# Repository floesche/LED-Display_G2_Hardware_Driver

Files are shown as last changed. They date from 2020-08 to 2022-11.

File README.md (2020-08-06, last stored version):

---
title: LED Array PCBs
parent: Generation 2
---

## Project content

```
├── led_array_3mm
│   └── gerber_v0p1
├── led_array_3mm_spacer
├── led_array_5mm
│   └── gerber_v0p1
├── led_array_5mm_adaptor
│   └── gerber_v0p1
├── led_array_5mm_mask
│   ├── arrayed
│   └── single
├── led_array_8x8_template
├── led_array_mixed
│   ├── gerber_v0p1
│   └── gerber_v0p2
├── led_array_sm0805
│   └── gerber_v0p1
└── pass_thru_panel
    └── gerber_v1p0
```

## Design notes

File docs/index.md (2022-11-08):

---
title: LED matrix
parent: Generation 2
nav_order: 5
---

# Custom LED matrix boards

Different pre-fabricated LED matrices are available, but their emitted light spectrum is not always well specified, might differ between production batches, and don't always align well with the sensitivity of a drosophila visual system. Around 2013 there was an effort to produce custom LED matrices for [Generation 2]({{site.baseurl}}/G2/) and [Generation 3]({{site.baseurl}}/G3/) display systems. The different versions listed below are plug-in replacements for pre-fabricated LED matrices and designed to be used with the [panel boards]({{site.baseurl}}/Generation%202/Panels/docs/).

1. TOC
{:toc}

## LED array TH 3mm

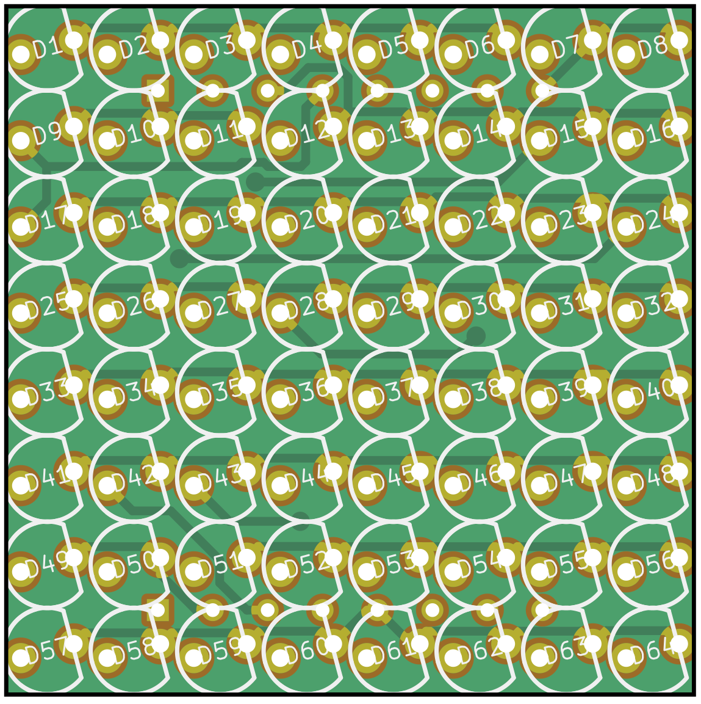
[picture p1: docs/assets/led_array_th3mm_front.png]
LED array through hole 3mm

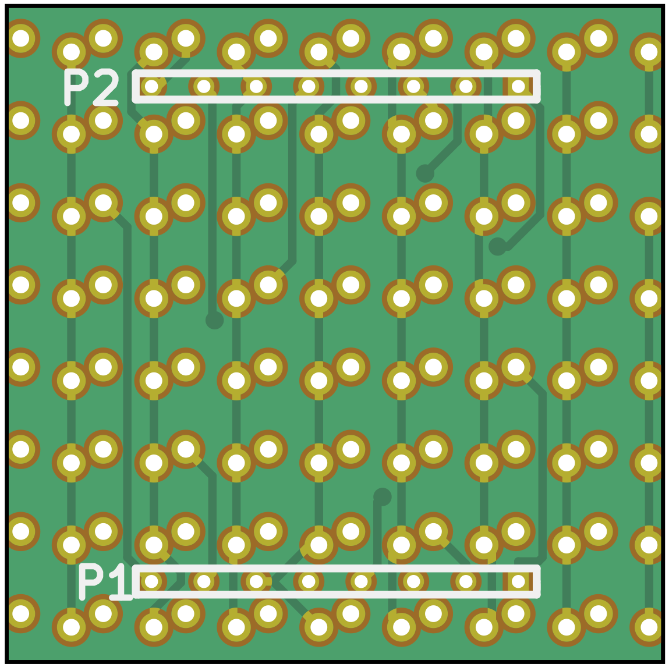
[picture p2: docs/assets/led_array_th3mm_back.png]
LED array through hole 3mm


The LED array TH 3mm is a LED matrix for through hole (TH) 3mm LEDs (have a [look at the schematics](assets/led_array_th3mm_schematic.pdf)). LEDs from many different manufacturers are available in this packages size.

Historic production ready files are archived at `led_array_th3mm/production_v1/`, yet it is unclear if there was ever a PCB produced.

The folder `led_array_th3mm/objects/` contains a vector graphic file, presumably used to laser cut a spacer to be used on top of the PCB (see [preview pdf](assets/led_array_th3mm_spacer.pdf)).

## LED array TH 5mm

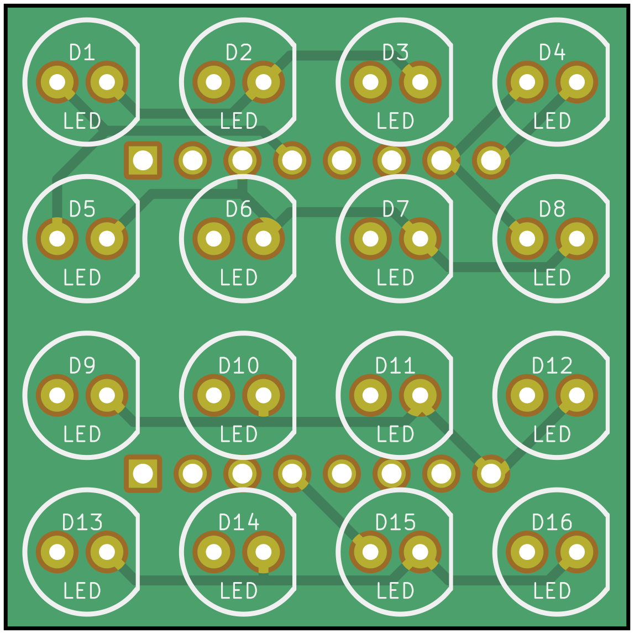
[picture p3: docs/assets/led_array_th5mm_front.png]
LED array through hole 5mm

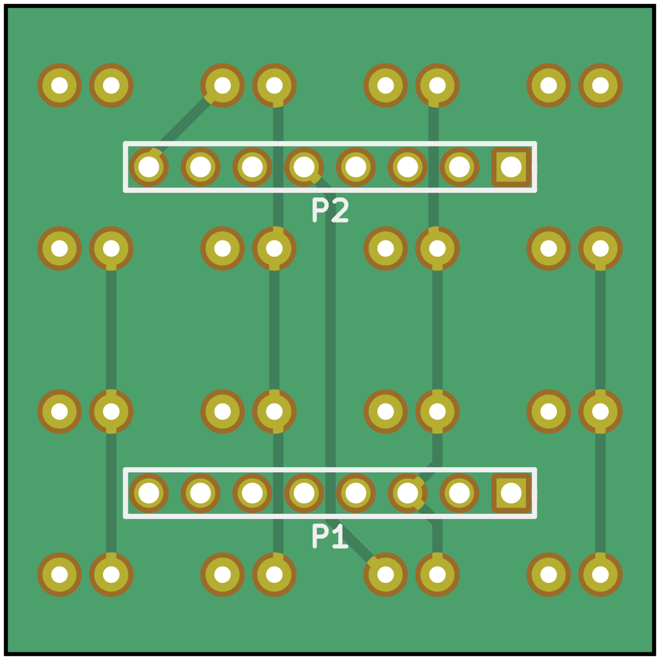
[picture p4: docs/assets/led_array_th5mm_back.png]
LED array through hole 5mm


The LED array TH 3mm is a LED matrix for through hole (TH) 5mm LEDs (have a [look at the schematics](assets/led_array_th5mm_schematic.pdf)). LEDs from many different manufacturers are available in this packages size. Because of the size constraints, only 4×4 LEDs fit on one of these matrices.

Historic production ready files are archived at `led_array_th5mm/production_v1/`, yet it is unclear if there was ever a PCB produced.

The folder `led_array_th5mm/objects/` contains different vector graphic file, presumably used to laser cut masks for the LEDs (see [preview pdf](assets/mask_inner_5mm.pdf)).

## LED array SMD 0805

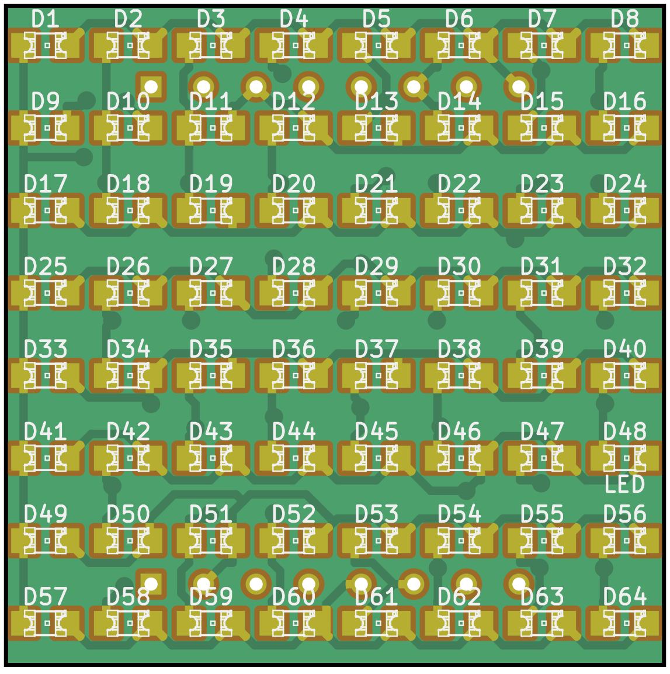
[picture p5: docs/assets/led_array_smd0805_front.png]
LED array SMD 0805

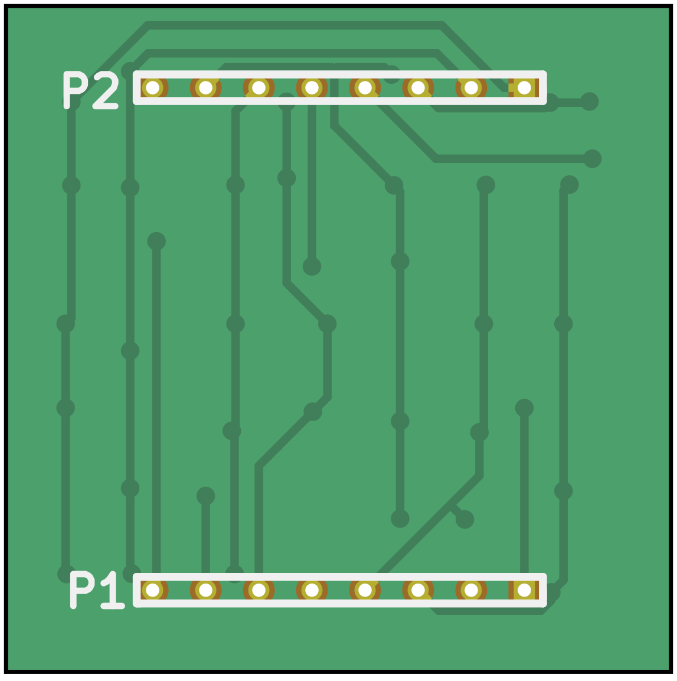
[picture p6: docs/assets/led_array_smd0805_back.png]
LED array SMD 0805


The LED array SMD 0805 is a LED matrix for surface mount devices with a package size of 0805 (have a [look at the schematics](assets/led_array_smd0805_schematic.pdf)). LEDs from many different manufacturers are available in this packages size.

Historic production ready files are archived at `led_array_smd0805/production_v1/`, yet it is unclear if there was ever a PCB produced.

## LED array SMD 1411-0805

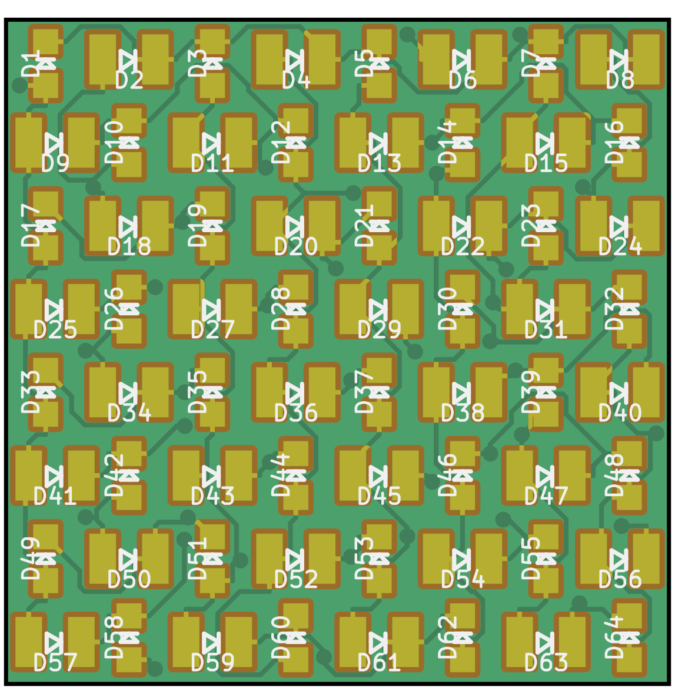
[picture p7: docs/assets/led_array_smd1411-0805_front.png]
LED array SMD 1411-0805

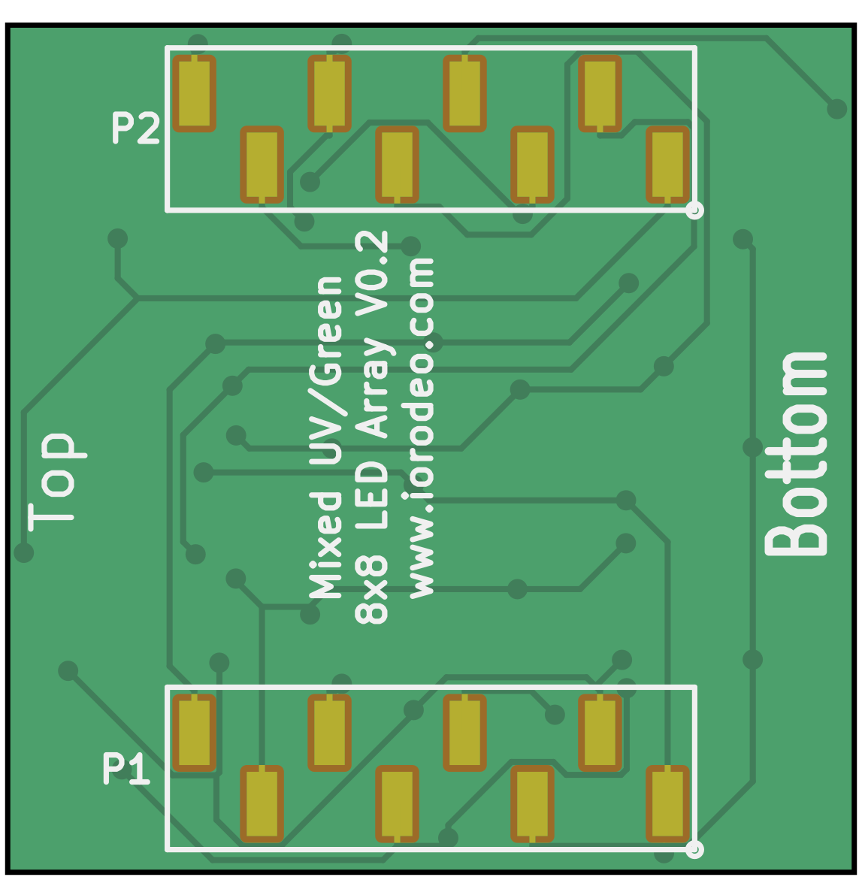
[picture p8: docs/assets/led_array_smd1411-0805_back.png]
LED array SMD 1411-0805


The LED array SMD 1411-0805 is a LED matrix for surface mount devices with alternating between packages size of 1411 and 0805 (have a [look at the schematics](assets/led_array_smd1411-0805_schematic.pdf)). This LED matrix was designer to use UV and green LEDs in the same matrix. The chosen UV LED by Yuli Tech with a spectrum peak at 365nm and product number __YLUV-365SMD__ has a SMD 1411 package size. There is a wide range of green LEDs in an 0805 package available, such as the Rohm __SML-210MTT86__ with a spectrum peak at 570nm.

Historic production ready files are archived at `led_array_smd0805/production_v0`. The most recently produced version was `led_array_smd1411-0805_v0p2.zip`.

## LED array template

The project folder `led_array_template` contains a 8×8 schematic that can be used as a template to produce different types of PCBs.

## Panel Adaptor

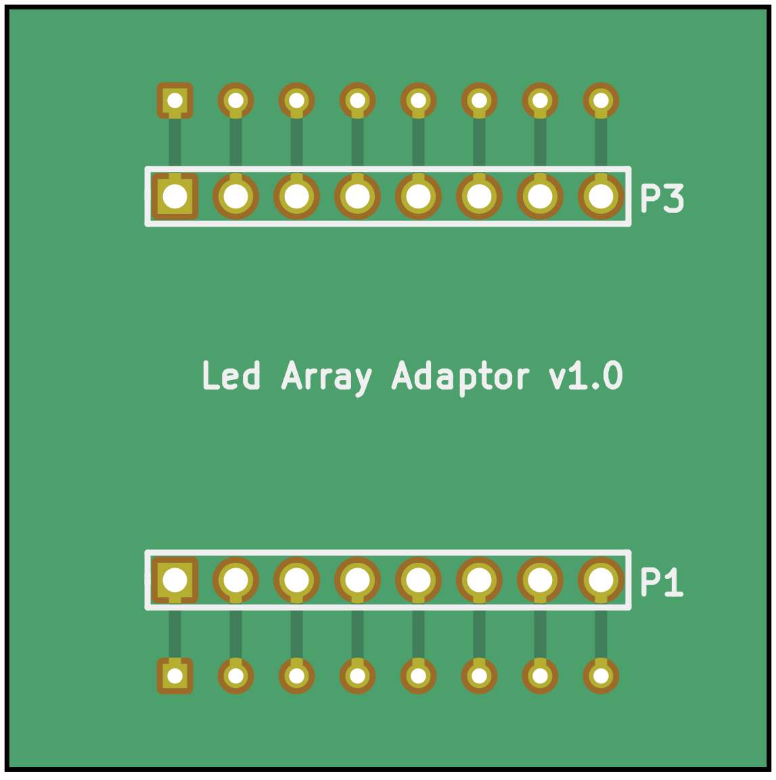
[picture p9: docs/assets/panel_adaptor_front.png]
Panel Adaptor Front

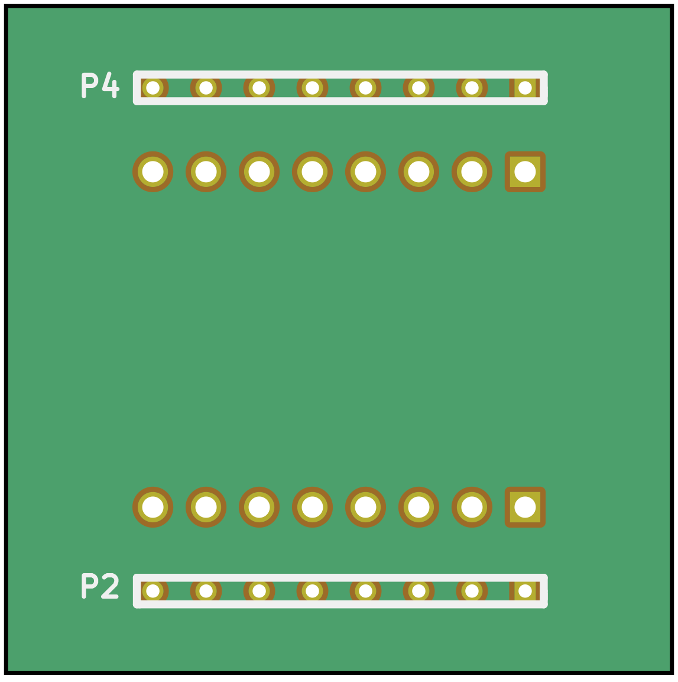
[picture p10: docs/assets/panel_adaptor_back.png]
Panel Adaptor Back


The `panel_adaptor` is a small PCB that allows an adaptation between different matrix sized and the [panel board]({{site.baseurl}}/Generation%202/Panels/docs/).

## Panel pass-thru

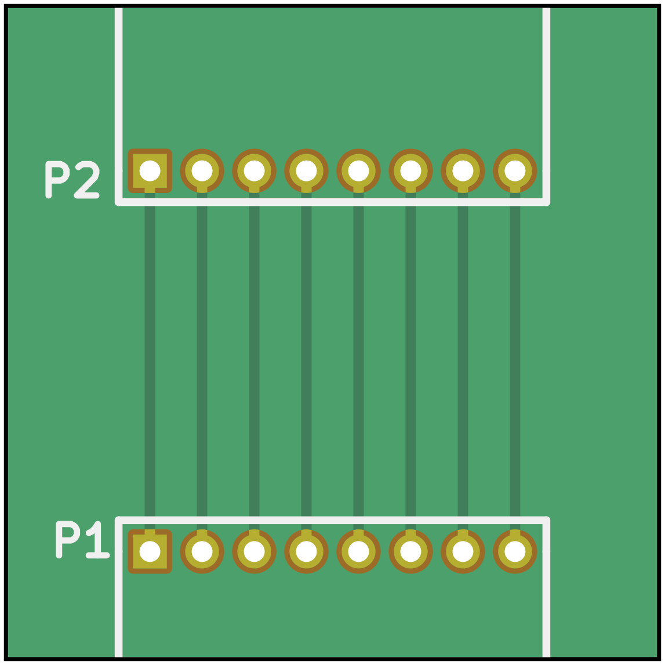
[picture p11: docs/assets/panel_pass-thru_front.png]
Panel pass-thru Front

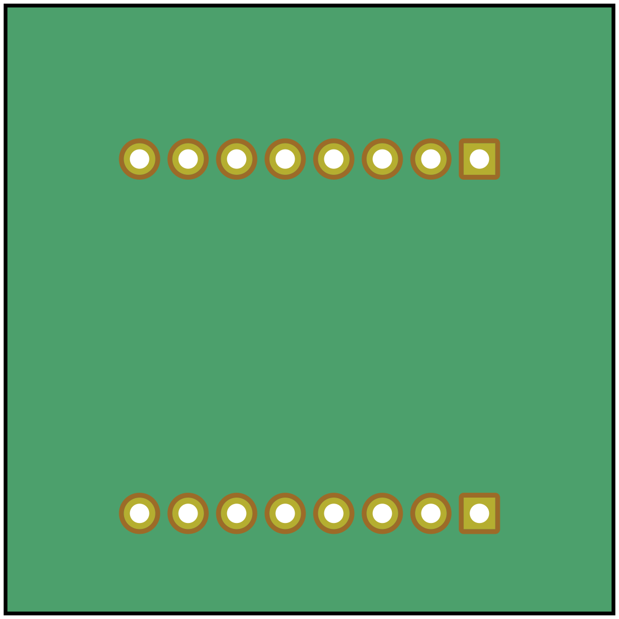
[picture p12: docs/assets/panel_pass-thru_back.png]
Panel pass-thru Back


The `panel_pass-thru` is a drop in replacement for a single display module. It carries the electrical signal to the next module, but does not display anything. This is similar to the [Generation 4 Window]({{site.baseurl}}/Generation%204/Hardware/docs/comm.html#window), but without the cutout in the center.

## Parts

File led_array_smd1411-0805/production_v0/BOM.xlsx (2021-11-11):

Item # | Qty | Reference | Descritpion | P/N | Vendor
1 | 32 | D1, D3, D5, D7, D10, D12, D14, D16, D17, D19, D21, D23, D26, D28, D30, D32, D33, D35, D37, D39, D42, D44, D46, D48, D49, D51, D53, D55, D58, D60, D62, D64 | LED 570nm (green) SMD 0805 | 511-1287-1-ND | Digikey
2 | 32 | D2, D4, D6, D8, D9, D11, D13, D15, D18, D20, D22, D24, D25, D27, D29, D31, D34, D36, D38, D40, D41, D43, D45, D47, D50, D52, D54, D56, D57, D59, D61, D63 | LED 365nm (UV) SMD | YLUV-365SMD | Shanghai Yuli Technology Co., Ltd (For contact information see below)
3 | 2 | P1, P2 | SMD header – 8 pos made from 64 pos breakaway | ED24064-ND | Digikey
Notes:
1.) Components P1 and P2 on the back side of the PCB are not to be included in the turn-key assembly.
2.) Shanghai Yuli Technology Co., Ltd. Contact: Luna Tang, Email: sales@yulitech.com, Tel: 0086 -21 33632320, Fax: 0086 21 33632320

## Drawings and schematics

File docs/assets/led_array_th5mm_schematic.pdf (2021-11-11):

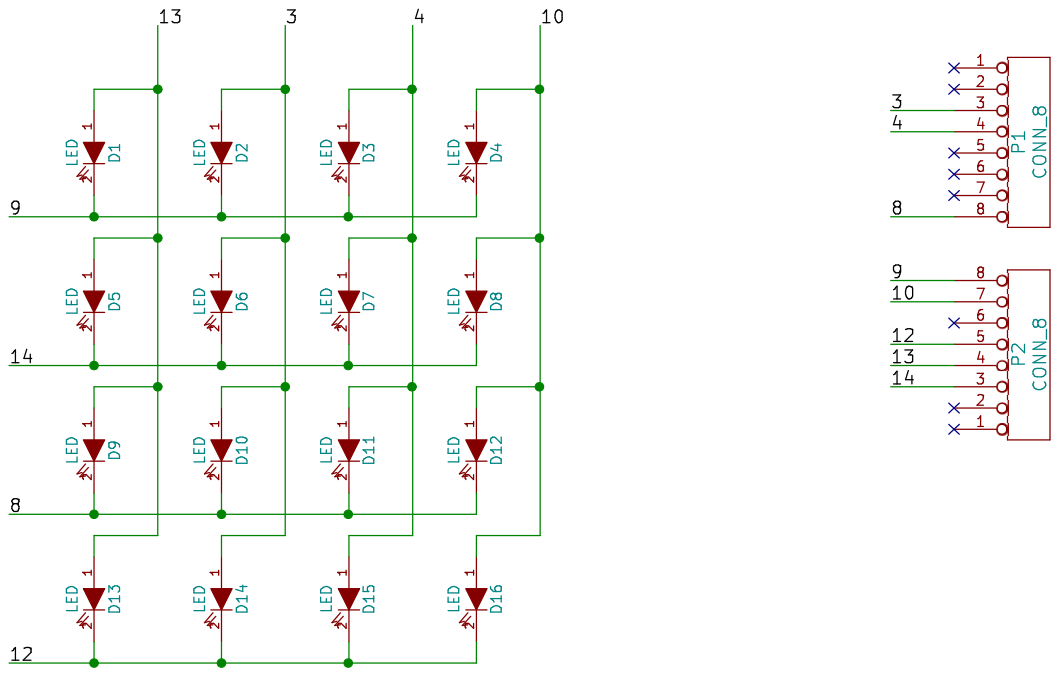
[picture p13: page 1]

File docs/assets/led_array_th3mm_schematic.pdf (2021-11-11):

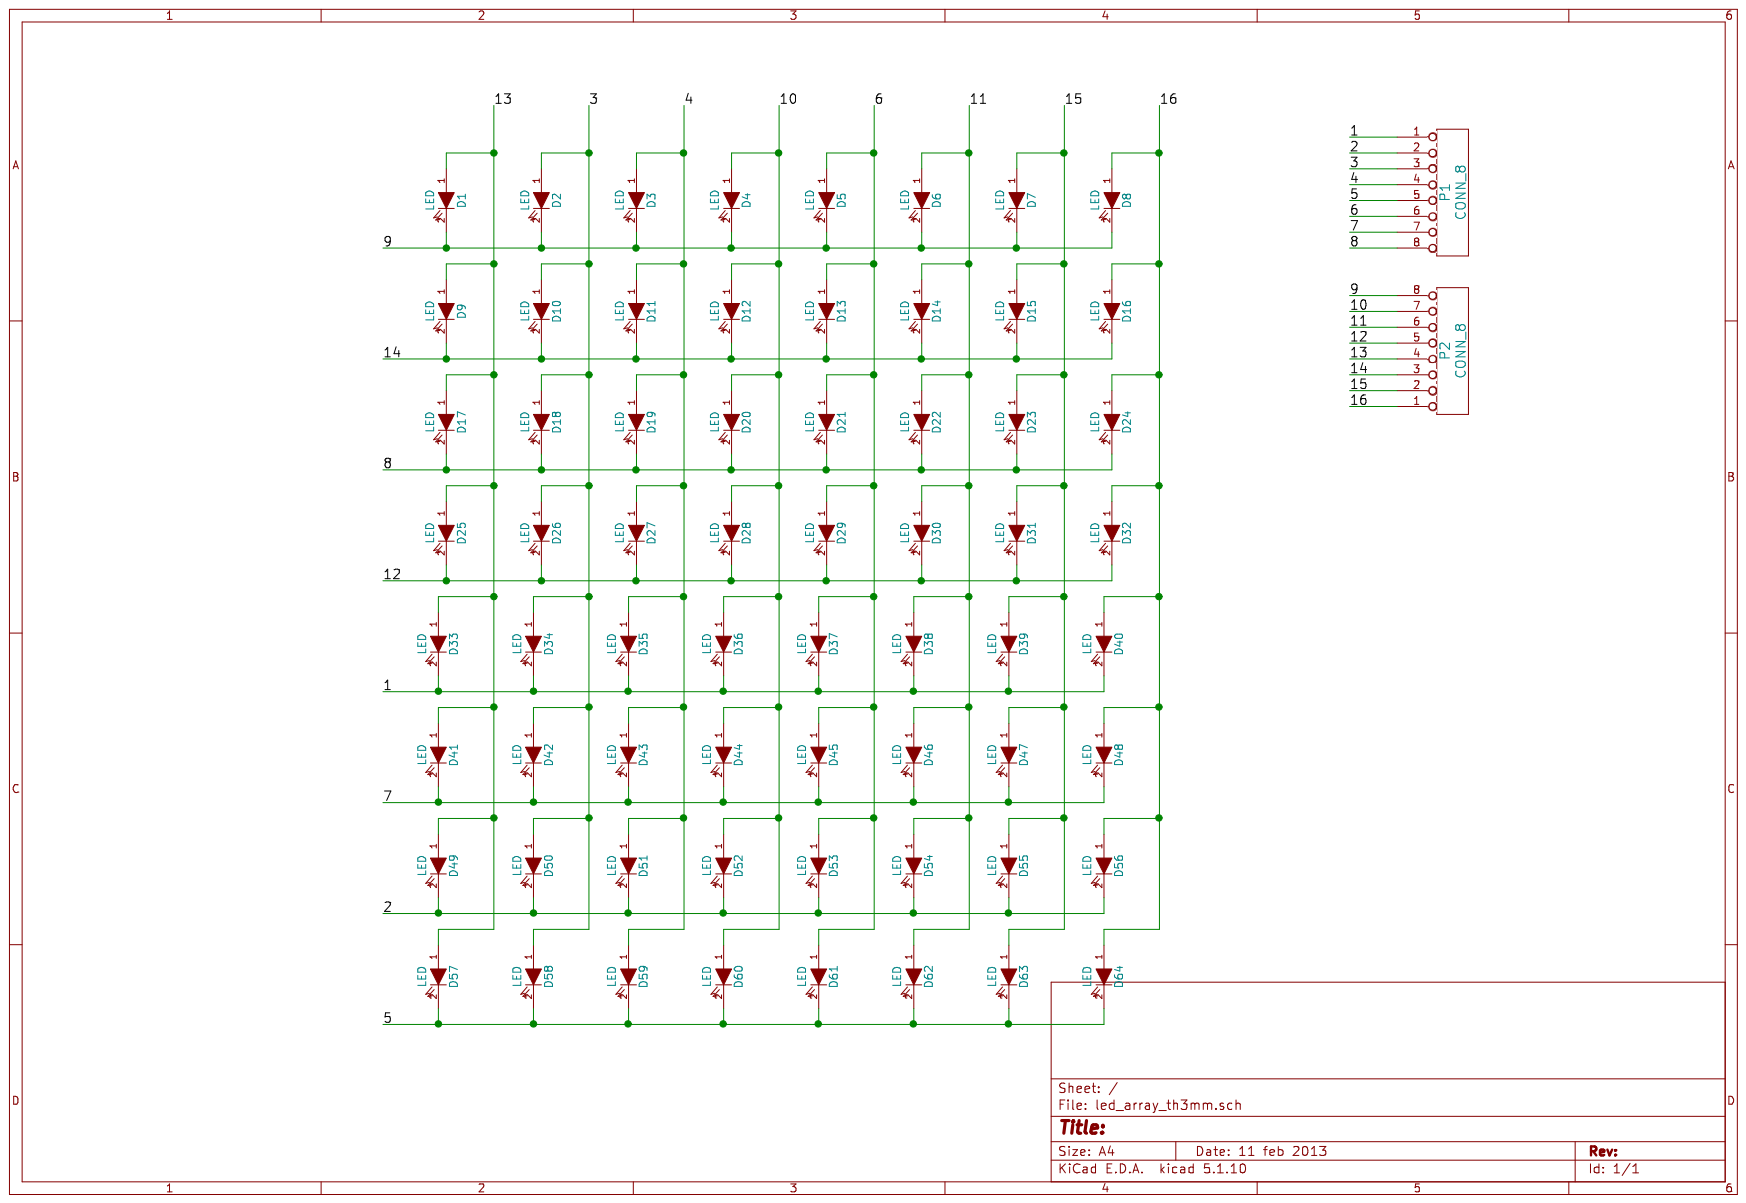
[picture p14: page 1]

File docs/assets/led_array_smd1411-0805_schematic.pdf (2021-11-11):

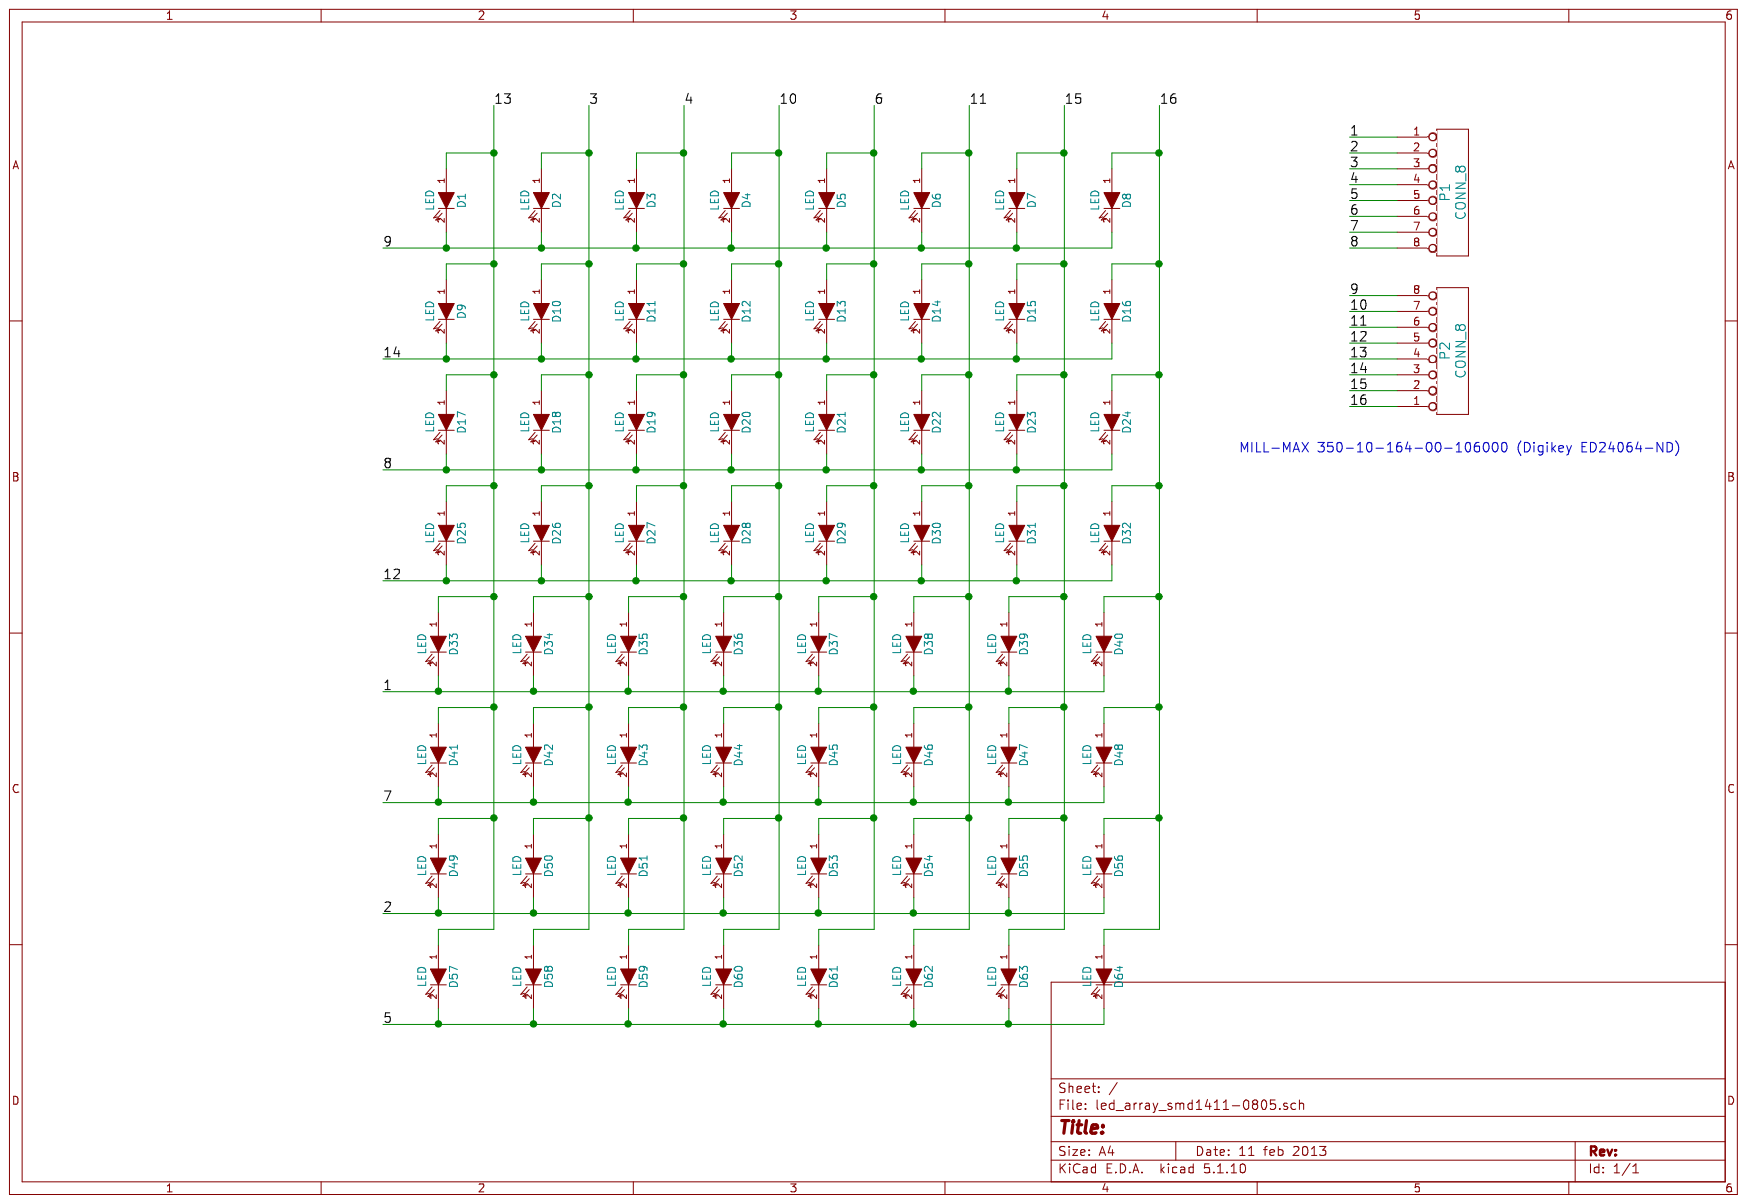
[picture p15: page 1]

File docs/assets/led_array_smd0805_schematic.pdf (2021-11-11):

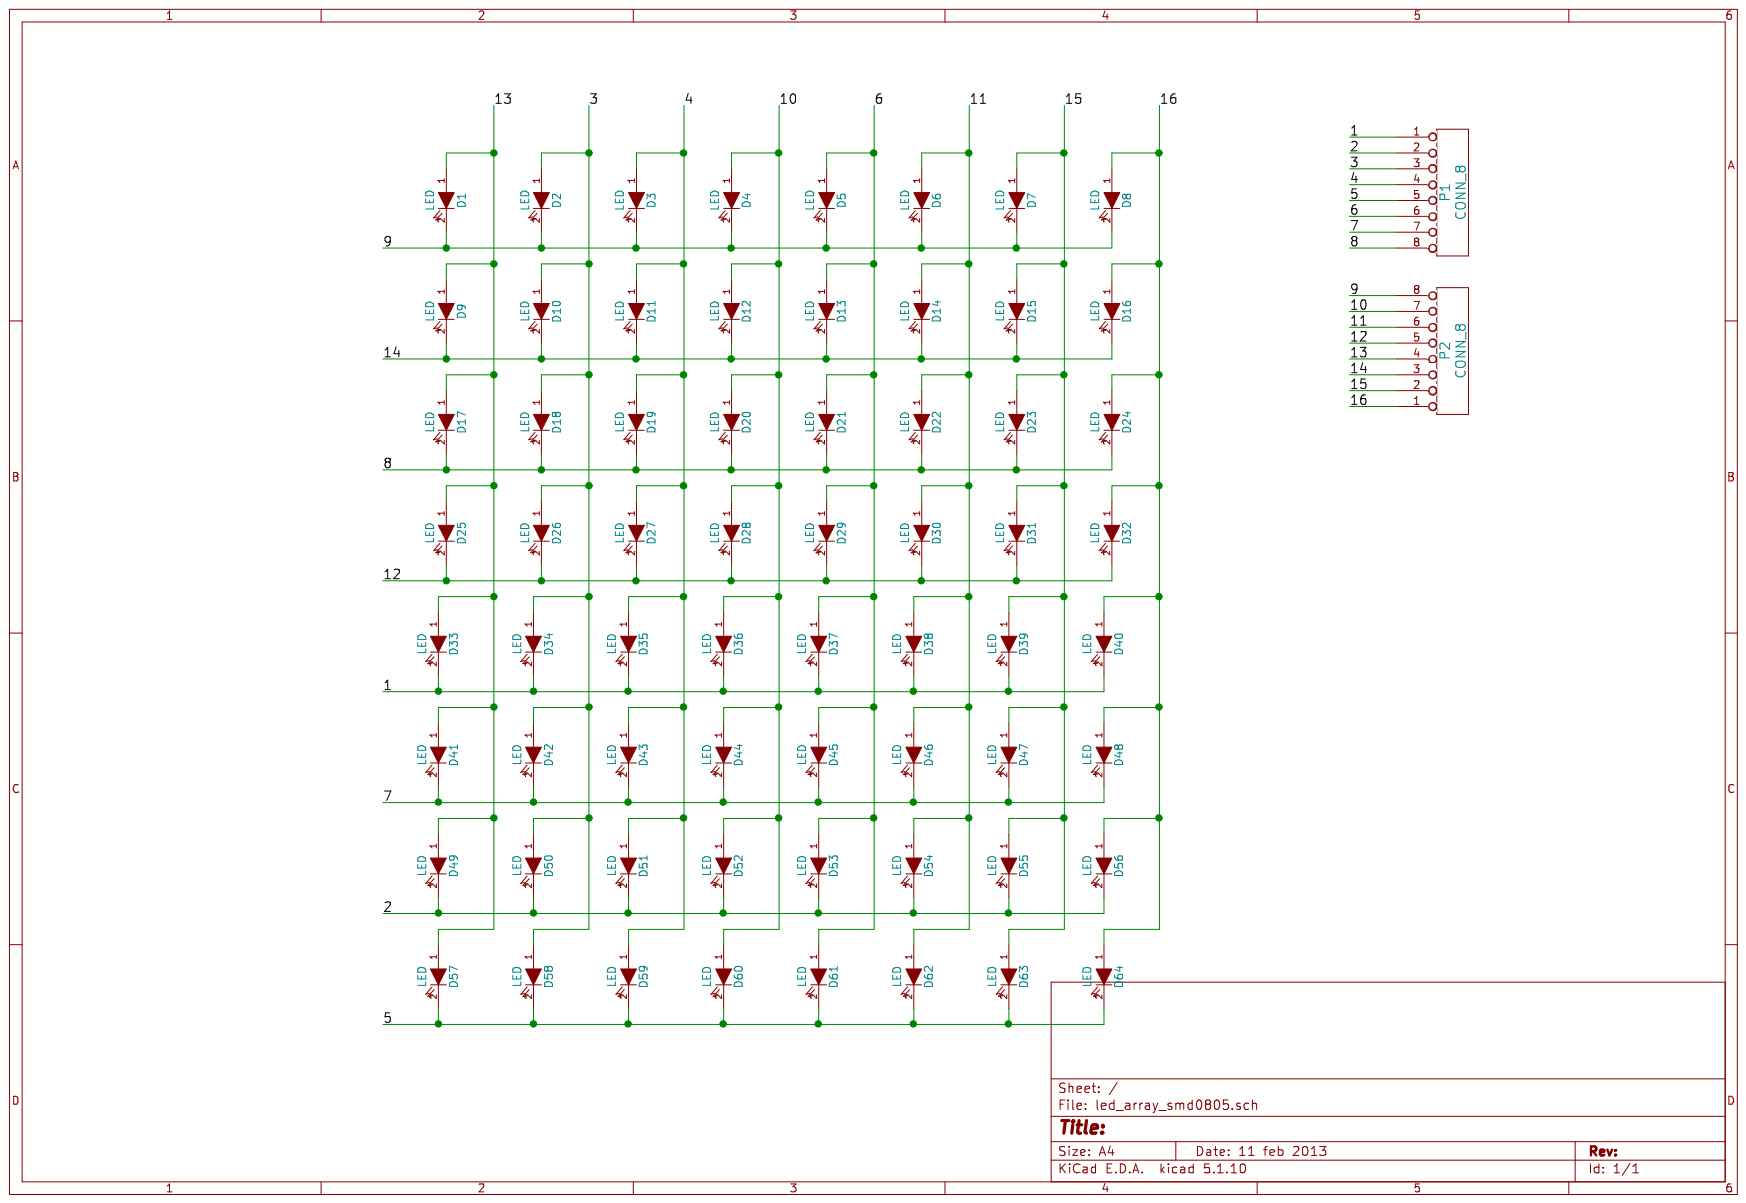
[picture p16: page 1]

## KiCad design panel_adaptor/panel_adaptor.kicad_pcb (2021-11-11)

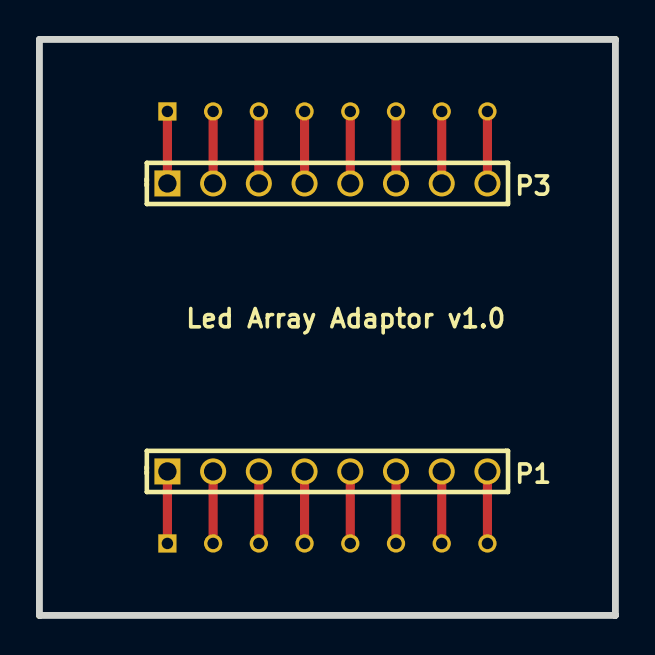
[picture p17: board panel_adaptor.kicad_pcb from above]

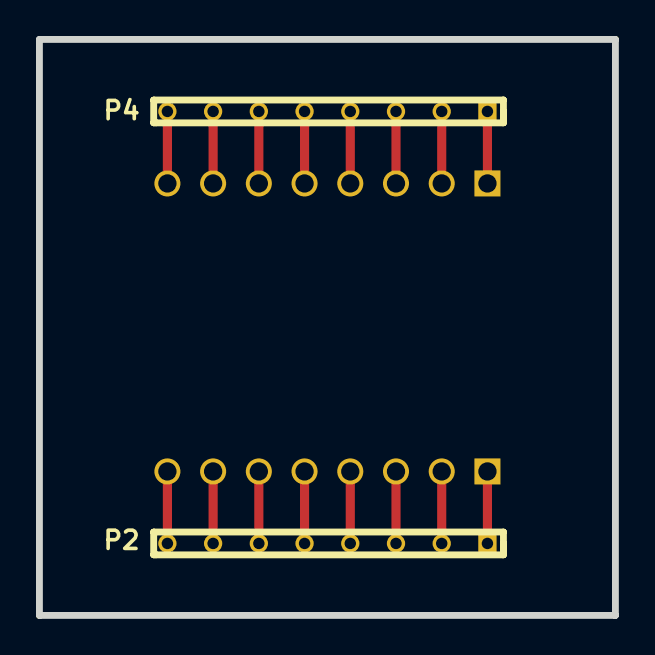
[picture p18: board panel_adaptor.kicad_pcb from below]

Board: 2 copper layers, 32.0 x 32.0 mm, 4 parts (2 on the bottom side), 16 nets.

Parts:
P1, P3: PIN_ARRAY-8X1
P2, P4: PANEL_HEADER_8PIN

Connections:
unnamed: P3.1, P4.1
unnamed: P3.2, P4.2
unnamed: P3.3, P4.3
unnamed: P3.4, P4.4
unnamed: P3.5, P4.5
unnamed: P3.6, P4.6
unnamed: P3.7, P4.7
unnamed: P3.8, P4.8
unnamed: P1.1, P2.1
unnamed: P1.2, P2.2
unnamed: P1.3, P2.3
unnamed: P1.4, P2.4
unnamed: P1.5, P2.5
unnamed: P1.6, P2.6
unnamed: P1.7, P2.7
unnamed: P1.8, P2.8

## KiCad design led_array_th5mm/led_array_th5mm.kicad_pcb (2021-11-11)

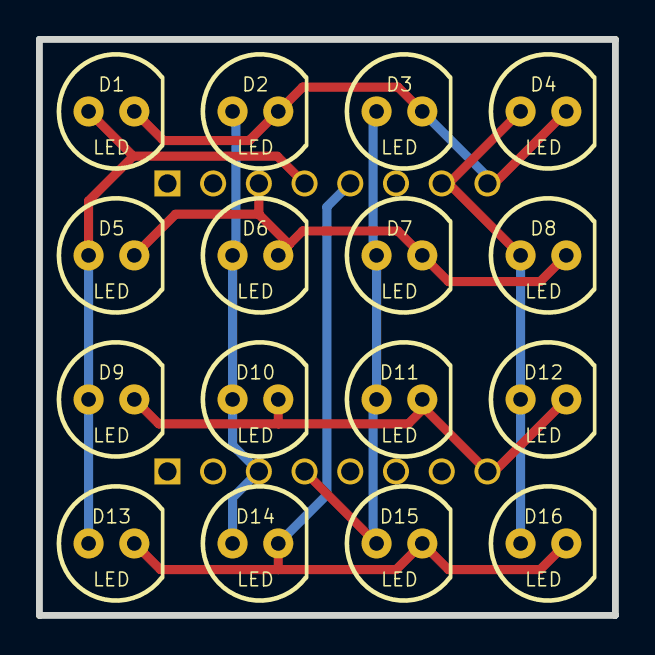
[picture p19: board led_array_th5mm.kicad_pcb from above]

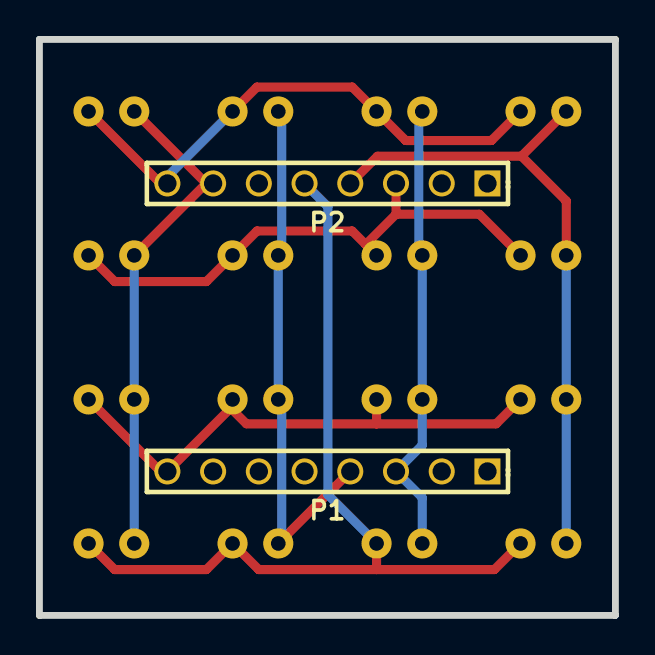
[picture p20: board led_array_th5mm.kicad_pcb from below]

Board: 2 copper layers, 32.0 x 32.0 mm, 18 parts (2 on the bottom side), 8 nets.

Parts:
D1, D2, D3, D4, D5, D6, D7, D8, D9, D10, D11, D12, D13, D14, D15, D16: LED; LED-5MM-MOD
P1, P2: PIN_ARRAY-8X1

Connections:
/3: D2.1, D6.1, D10.1, D14.1, P1.3
/4: D3.1, D7.1, D11.1, D15.1, P1.4
/8: D9.2, D10.2, D11.2, D12.2, P1.8
/9: D1.2, D2.2, D3.2, D4.2, P2.8
/10: D4.1, D8.1, D12.1, D16.1, P2.7
/12: D13.2, D14.2, D15.2, D16.2, P2.5
/13: D1.1, D5.1, D9.1, D13.1, P2.4
/14: D5.2, D6.2, D7.2, D8.2, P2.3

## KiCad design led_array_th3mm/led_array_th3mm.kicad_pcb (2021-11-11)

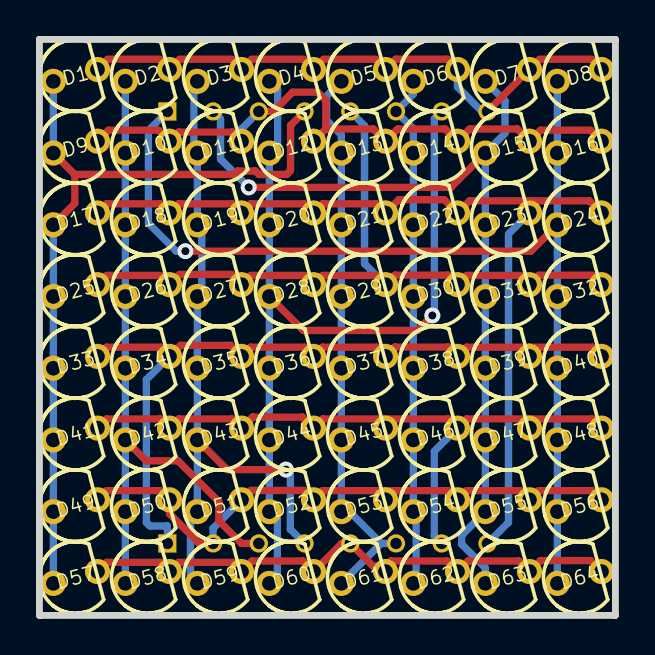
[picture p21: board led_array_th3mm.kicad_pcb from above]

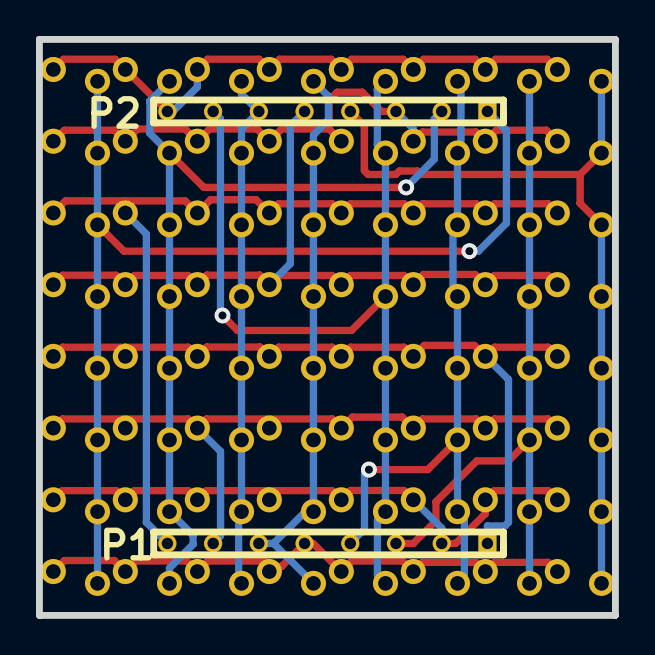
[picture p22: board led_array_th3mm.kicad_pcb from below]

Board: 2 copper layers, 32.0 x 32.0 mm, 66 parts (2 on the bottom side), 16 nets.

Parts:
D1, D2, D3, D4, D5, D6, D7, D8, D9, D10, D11, D12, D13, D14, D15, D16, D17, D18, D19, D20, D21, D22, D23, D24, D25, D26, D27, D28, D29, D30, D31, D32, D33, D34, D35, D36, D37, D38, D39, D40, D41, D42, D43, D44, D45, D46, D47, D48, D49, D50, D51, D52, D53, D54, D55, D56, D57, D58, D59, D60, D61, D62, D63, D64: LED; LED-3MM-MOD
P1, P2: PANEL_HEADER_8PIN

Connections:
/1: D33.2, D34.2, D35.2, D36.2, D37.2, D38.2, D39.2, D40.2, P1.1
/2: D49.2, D50.2, D51.2, D52.2, D53.2, D54.2, D55.2, D56.2, P1.2
/3: D2.1, D10.1, D18.1, D26.1, D34.1, D42.1, D50.1, D58.1, P1.3
/4: D3.1, D11.1, D19.1, D27.1, D35.1, D43.1, D51.1, D59.1, P1.4
/5: D57.2, D58.2, D59.2, D60.2, D61.2, D62.2, D63.2, D64.2, P1.5
/6: D5.1, D13.1, D21.1, D29.1, D37.1, D45.1, D53.1, D61.1, P1.6
/7: D41.2, D42.2, D43.2, D44.2, D45.2, D46.2, D47.2, D48.2, P1.7
/8: D17.2, D18.2, D19.2, D20.2, D21.2, D22.2, D23.2, D24.2, P1.8
/9: D1.2, D2.2, D3.2, D4.2, D5.2, D6.2, D7.2, D8.2, P2.8
/10: D4.1, D12.1, D20.1, D28.1, D36.1, D44.1, D52.1, D60.1, P2.7
/11: D6.1, D14.1, D22.1, D30.1, D38.1, D46.1, D54.1, D62.1, P2.6
/12: D25.2, D26.2, D27.2, D28.2, D29.2, D30.2, D31.2, D32.2, P2.5
/13: D1.1, D9.1, D17.1, D25.1, D33.1, D41.1, D49.1, D57.1, P2.4
/14: D9.2, D10.2, D11.2, D12.2, D13.2, D14.2, D15.2, D16.2, P2.3
/15: D7.1, D15.1, D23.1, D31.1, D39.1, D47.1, D55.1, D63.1, P2.2
/16: D8.1, D16.1, D24.1, D32.1, D40.1, D48.1, D56.1, D64.1, P2.1

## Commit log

2021-11-11 cleanup 3mm
    [led_array.brd, led_array.dsn, led_array.kicad_pcb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]
2021-11-11 add footprint library
2021-11-11 5mm cleanup
    [led_array.brd, led_array.dsn, led_array.kicad_pcb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]
2021-11-11 cleanup adaptor
    [led_array_adaptor.brd, led_array_adaptor.kicad_pcb, led_array_adaptor.sch]
2021-11-11 clean up template
    [led_array.brd, led_array.dsn, led_array.kicad_pcb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]
2021-11-11 cleanup mixed
    [led_array.brd, led_array.dsn, led_array.sch]
2021-11-11 cleanup sm0805
    [led_array.brd, led_array.dsn, led_array.kicad_pcb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]
2021-11-11 cleanup pass thru
    [$savepcb.brd, pass_thru_panel.brd, pass_thru_panel.kicad_pcb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]
2021-11-11 project renames
    [BOM.xls, BOM_led_array_mixed_v0p1.xls, BOM_led_array_mixed_v0p2.xls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]
2021-11-11 add 0805 documentation
    [led_array_smd0805-Back.gbl, led_array_smd0805-Front.gtl, led_array_smd0805-Mask_Back.gbs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]
2021-11-11 start 1411 0805 documentation
    [BOM_led_array_mixed_v0p1.xls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]
2021-11-11 move production files
    [BOM_led_array_mixed_v0p1.xls, BOM_led_array_mixed_v0p2.xls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]
2021-11-11 rename production files
    [BOM.xls, BOM.xlsx, BOM_led_array_mixed_v0p2.xls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]
2021-11-11 rename template
    [led_array_template.kicad_pcb, led_array_template.sch]
2021-11-11 project rename
    [led_array-Back.gbl, led_array-Front.gtl, led_array-Mask_Back.gbs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]
2021-11-11 docs for 5mm
    [led_array_th5mm-Back.gbl, led_array_th5mm-Front.gtl, led_array_th5mm-Mask_Back.gbs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]
2021-11-11 rename panel adaptor
    [panel_adaptor-Back.gbl, panel_adaptor-Front.gtl, panel_adaptor-Mask_Back.gbs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]
2021-11-11 improve pass through documentation
    [panel_pass-thru-Back.gbl, panel_pass-thru-Front.gtl, panel_pass-thru-Mask_Back.gbs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]
